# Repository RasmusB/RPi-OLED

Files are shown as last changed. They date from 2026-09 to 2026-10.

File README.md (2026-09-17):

# RPi-OLED Readme

Adapter board for using a generic OLED with a Raspberry Pi

> [!WARNING]
> Before using this repo, make sure to run the 'setup-hooks.sh' script first.

## Release notes

Releases are tagged using custom [Semantic Versioning rules](./Doc/SemVer%20Rules.md).

### 0.1.0

- TODO: List features that are introduced / removed
  - Focus on changes that would affect the end user, and indicate *how* they will be affected.
  - For example, don't write 'R2 changed to pull-down', but instead: 'Board will enter the bootloader when the user pushes SW1'.
  - More detailed change notes goes into the version history table in the schematic.

## Git behaviour

There are some pre-commit hooks in the .git folder. These will attempt to enforce a few sanity rules based on the following rules.

### The `main` branch must only contain releases of production files

- Commits to `main` are not allowed
- TODO: Commits must be tagged to generate production files (at least on the main branch)
- TODO: Tags must follow the pattern `vX.Y.Z` (see the [SemVer rules](./Doc/SemVer%20Rules.md) for details)

### Development happens in a `dev` branch

- All check-ins during development are made on the `dev` branch. The `dev` branch is merged into `main` when (and only when) the production files are ready for release.
- Any tags created on the dev branch *must not* match the pattern `vX.Y.Z` to ensure they are not confused for proper release tags
- Merging to main is not allowed if there are any failing tests (ERC, DRC, etc.)

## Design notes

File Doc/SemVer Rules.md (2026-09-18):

# SemVer Rules

These are the guidelines to determine the next tag number. Tags are validated against [this regex](https://regex101.com/r/iSM7DD/2).

## Major changes

This is used for major changes in mechanical or electrical behaviour that makes the board *incompatible* with previous use cases.

- Changes in the outline and/or component placement that makes the new version incompatible with existing enclosures
- Electrical changes in IO interfaces that makes the board incompatible with auxiliary equipment used with the last version
- Adding a end user interface

## Minor changes

This is meant for smaller changes that are meant to be included in the next production batch. The production release files will always have '0' as the patch revision.

- Any changes to the PCB: changed routing, stackup, board finish etc.
- Mechanical changes that does not cause mechanical issues
- BOM changes

## Patches

These are any patches that have been applied to a production board. It can be thought of as a simple issue tracker to document what needs to be updated before the next release of production files.

- Swapped components
- Changed solder jumpers
- Cut/patched traces
- Installed THT components

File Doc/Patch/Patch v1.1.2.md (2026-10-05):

# RPi-OLED Adapter v1.1.1 Patches

```foam-query
filter:
  and:
    - tag: "#errata"
    - jexl: "'v1.1.2' in resource.properties.patched_in"
select:
  - field: title
  - field: properties.workaround
    label: Immediate Workaround / Patch
  - field: properties.fixed_in
    label: Fixed in
format: table

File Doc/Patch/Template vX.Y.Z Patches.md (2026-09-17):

# [Project name] [vX.Y.Z] Patches

Example patch below

## Change I2C pullups

The I2C bus does not work reliably.

### Instructions

Change R1 and R2 according to BOM

[Image showing component placement if needed]

### BOM

| Designator | Old MPN | New MPN |
| --- | --- | --- |
| R1, R2 | RES04021k00 | RES04024k70 |

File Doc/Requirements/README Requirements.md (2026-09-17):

# README Requirements

## Naming and versioning

The requirements document shall be named as:

`[Project Name] Requirements v1.0.0`

The version in the filename indicates the version of the document itself and does not necessarily track the release tags, but there is some correlation:

- The **major** part increases when there are changes that force a new major release of the board.
- The **minor** part is updated for most other changes - new requirements, changed acceptance criteria etc.
- The **subrevision** is updated for any changes that don't affect the technical requirements or implementation. This can include (but is not limited to) spelling and formatting.

All requirements shall be numbered according to their category. A number is never reused - if a specific requirement becomes obsolete, it is instead marked as such.

## Requirement tags

There are some markers on each requirement.

### Validation level

| Tag |

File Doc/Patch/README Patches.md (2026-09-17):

# README Patches

New patch notes are created with the following file name pattern:

`[Project Name] [Tag] Patches.md`

Where `[Project Name]` is the name of the repository, and `[Tag]` is the version number of the board *after* applying the patch, i.e. `v1.2.3`. There should never be a 'patch 0', since that is reserved for release packages.

## Example content

```text
.
└── [Project name]
    └── Doc
        └── Patch
            ├── [Project name] v1.0.1 Patch.md
            ├── [Project name] v1.1.1 Patch.md
            ├── [Project name] v1.2.1 Patch.md
            └── ...
```

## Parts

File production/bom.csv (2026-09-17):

Designator | Footprint | Quantity | Value | LCSC Part #
C1, C2, C3, C4, C5, C6, C7 | 0402 | 7 | 100n | C1525
J1 | PinSocket_2x20_P2.54mm_Vertical | 1 | GPIO
J2 | Hirose_FH12-22S-0.5SH_1x22-1MP_P0.50mm_Horizontal | 1 | DSI IN | C597981
J9 | Hirose_FH26-39S-0.3SHW_2Rows-39Pins-1MP_P0.60mm_Horizontal | 1 | OLED_H497TLB01 | C92280
R1, R2, R7, R8 | 0402 | 4 | 3.9k | C11925
R3, R5 | 0402 | 2 | 10k | C25531
R4, R6 | 0402 | 2 | 12k1 | C25852
U1 | SOIC-8_5.3x5.3mm_P1.27mm | 1 | CAT24C256 | C79987
U2 | VSSOP-8_3x3mm_P0.65mm | 1 | TCA9800 | C2677364
U3 | SOT-23-5 | 1 | TPS76318 | C7099
U4 | SOT-23-6 | 1 | TPS22917DBV | C2681320

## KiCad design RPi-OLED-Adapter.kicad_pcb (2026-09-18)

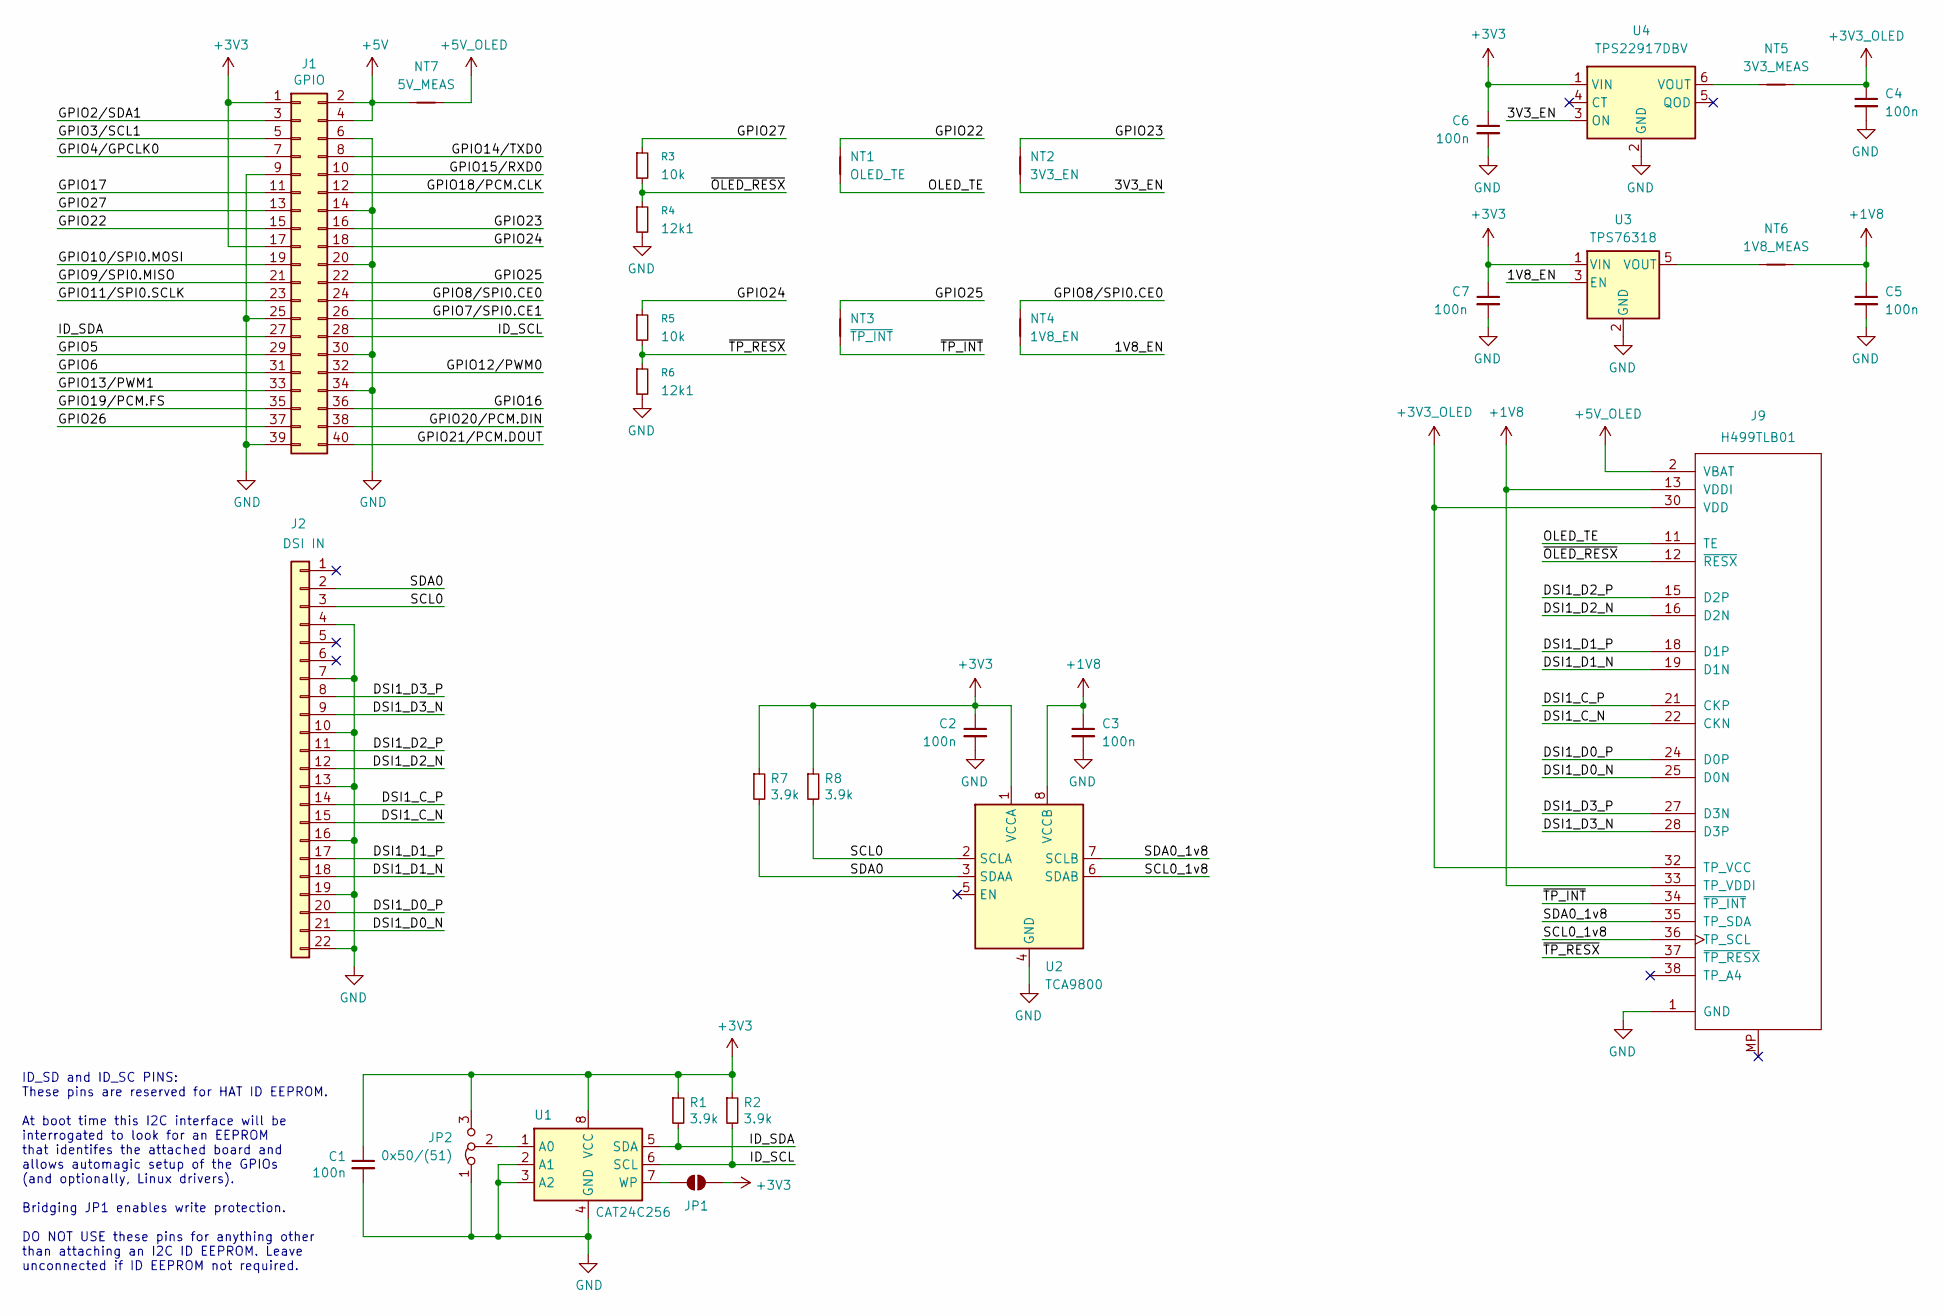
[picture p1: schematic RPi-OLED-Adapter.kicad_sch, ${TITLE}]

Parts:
C1, C2, C3, C4, C5, C6, C7: 100n; C_0402_1005Metric; MPN CL05B104KO5NNNC; LCSC Part # C1525
J1: GPIO; PinSocket_2x20_P2.54mm_Vertical; MPN 2541FV-2x20P-B; LCSC Part # C25503128
J2: DSI IN; Hirose_FH12-22S-0.5SH_1x22-1MP_P0.50mm_Horizontal; MPN FH12-22S-0.5SH(55); LCSC Part # C597981
J9: H499TLB01; Hirose_FH26-39S-0.3SHW_2Rows-39Pins-1MP_P0.60mm_Horizontal; MPN FH26W-39S-0.3SHW(60); LCSC Part # C92280
JP1: ID_WP; SolderJumper-2_P1.3mm_Bridged_RoundedPad1.0x1.5mm
JP2: 0x50/(51); SolderJumper-3_P1.3mm_Bridged12_RoundedPad1.0x1.5mm
NT1: OLED_TE; SolderJumper-2_P1.3mm_Bridged_RoundedPad1.0x1.5mm
NT2: 3V3_EN; SolderJumper-2_P1.3mm_Bridged_RoundedPad1.0x1.5mm
NT3: ~{TP_INT}; SolderJumper-2_P1.3mm_Bridged_RoundedPad1.0x1.5mm
NT4: 1V8_EN; SolderJumper-2_P1.3mm_Bridged_RoundedPad1.0x1.5mm
NT5: 3V3_MEAS; SolderJumper-2_P1.3mm_Bridged_RoundedPad1.0x1.5mm
NT6: 1V8_MEAS; SolderJumper-2_P1.3mm_Bridged_RoundedPad1.0x1.5mm
NT7: 5V_MEAS; SolderJumper-2_P1.3mm_Bridged_RoundedPad1.0x1.5mm
R1, R2, R7, R8: 3.9k; R_0402_1005Metric; MPN 0402WGJ0392TCE; LCSC Part # C11925
R3, R5: 10k; R_0402_1005Metric; MPN 0402WGJ0103TCE; LCSC Part # C25531
R4, R6: 12k1; R_0402_1005Metric; MPN 0402WGF1212TCE; LCSC Part # C25852
U1: CAT24C256; SOIC-8_5.3x5.3mm_P1.27mm; MPN CAT24C256WI-GT3; LCSC Part # C79987
U2: TCA9800; VSSOP-8_3x3mm_P0.65mm; MPN TCA9800DGKR; LCSC Part # C2677364
U3: TPS76318; SOT-23-5; MPN TPS76318DBVR; LCSC Part # C7099
U4: TPS22917DBV; SOT-23-6; MPN TPS22917DBVR; LCSC Part # C2681320

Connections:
+1V8: C3.1, C5.1, J9.13 (VDDI), J9.33 (TP_VDDI), NT6.2, U2.8 (VCCB)
+3V3: C1.1, C2.1, C6.1, C7.1, J1.1, J1.17, JP1.2 (B), JP2.3 (B), R1.1, R2.1, R7.1, R8.1, U1.8 (VCC), U2.1 (VCCA), U3.1 (VIN), U4.1 (VIN)
+3V3_OLED: C4.1, J9.30 (VDD), J9.32 (TP_VCC), NT5.2
+5V: J1.2, J1.4, NT7.1
+5V_OLED: J9.2 (VBAT), J9.3 (VBAT), J9.4 (VBAT), J9.5 (VBAT), J9.6 (VBAT), NT7.2
/1V8_EN: NT4.1, U3.3 (EN)
/3V3_EN: NT2.1, U4.3 (ON)
/DSI1_C_N: J2.15, J9.22 (CKN)
/DSI1_C_P: J2.14, J9.21 (CKP)
/DSI1_D0_N: J2.21, J9.25 (D0N)
/DSI1_D0_P: J2.20, J9.24 (D0P)
/DSI1_D1_N: J2.18, J9.19 (D1N)
/DSI1_D1_P: J2.17, J9.18 (D1P)
/DSI1_D2_N: J2.12, J9.16 (D2N)
/DSI1_D2_P: J2.11, J9.15 (D2P)
/DSI1_D3_N: J2.9, J9.28 (D3P)
/DSI1_D3_P: J2.8, J9.27 (D3N)
/GPIO2/SDA1: J1.3
/GPIO3/SCL1: J1.5
/GPIO4/GPCLK0: J1.7
/GPIO5: J1.29
/GPIO6: J1.31
/GPIO7/SPI0.CE1: J1.26
/GPIO8/SPI0.CE0: J1.24, NT4.2
/GPIO9/SPI0.MISO: J1.21
/GPIO10/SPI0.MOSI: J1.19
/GPIO11/SPI0.SCLK: J1.23
/GPIO12/PWM0: J1.32
/GPIO13/PWM1: J1.33
/GPIO14/TXD0: J1.8
/GPIO15/RXD0: J1.10
/GPIO16: J1.36
/GPIO17: J1.11
/GPIO18/PCM.CLK: J1.12
/GPIO19/PCM.FS: J1.35
/GPIO20/PCM.DIN: J1.38
/GPIO21/PCM.DOUT: J1.40
/GPIO22: J1.15, NT1.2
/GPIO23: J1.16, NT2.2
/GPIO24: J1.18, R5.1
/GPIO25: J1.22, NT3.2
/GPIO26: J1.37
/GPIO27: J1.13, R3.1
/ID_SCL: J1.28, R2.2, U1.6 (SCL)
/ID_SDA: J1.27, R1.2, U1.5 (SDA)
/OLED_TE: J9.11 (TE), NT1.1
/SCL0: J2.3, R8.2, U2.2 (SCLA)
/SCL0_1v8: J9.36 (TP_SCL), U2.6 (SDAB)
/SDA0: J2.2, R7.2, U2.3 (SDAA)
/SDA0_1v8: J9.35 (TP_SDA), U2.7 (SCLB)
/~OLED_RESX: J9.12 (~RESX), R3.2, R4.1
/~TP_INT: J9.34 (~TP_INT), NT3.1
/~TP_RESX: J9.37 (~TP_RESX), R5.2, R6.1
GND: C1.2, C2.2, C3.2, C4.2, C5.2, C6.2, C7.2, J1.6, J1.9, J1.14, J1.20, J1.25, J1.30, J1.34, J1.39, J2.4, J2.7, J2.10, J2.13, J2.16, J2.19, J2.22, J9.1 (GND), J9.7 (GND), J9.8 (GND), J9.9 (GND), J9.14 (GND), J9.17 (GND), J9.20 (GND), J9.23 (GND), J9.26 (GND), J9.29 (GND), J9.31 (GND), J9.39 (GND), JP2.1 (A), R4.2, R6.2, U1.2 (A1), U1.3 (A2), U1.4 (GND), U2.4 (GND), U3.2 (GND), U4.2 (GND)
unnamed: JP1.1 (A), U1.7 (WP)
unnamed: JP2.2 (C), U1.1 (A0)
unnamed: NT6.1, U3.5 (VOUT)
unnamed: NT5.1, U4.6 (VOUT)

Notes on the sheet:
ID_SD and ID_SC PINS: These pins are reserved for HAT ID EEPROM. At boot time this I2C interface will be interrogated to look for an EEPROM that identifes the attached board and allows automagic setup of the GPIOs (and optionally, Linux drivers). Bridging JP1 enables write protection. DO NOT USE th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

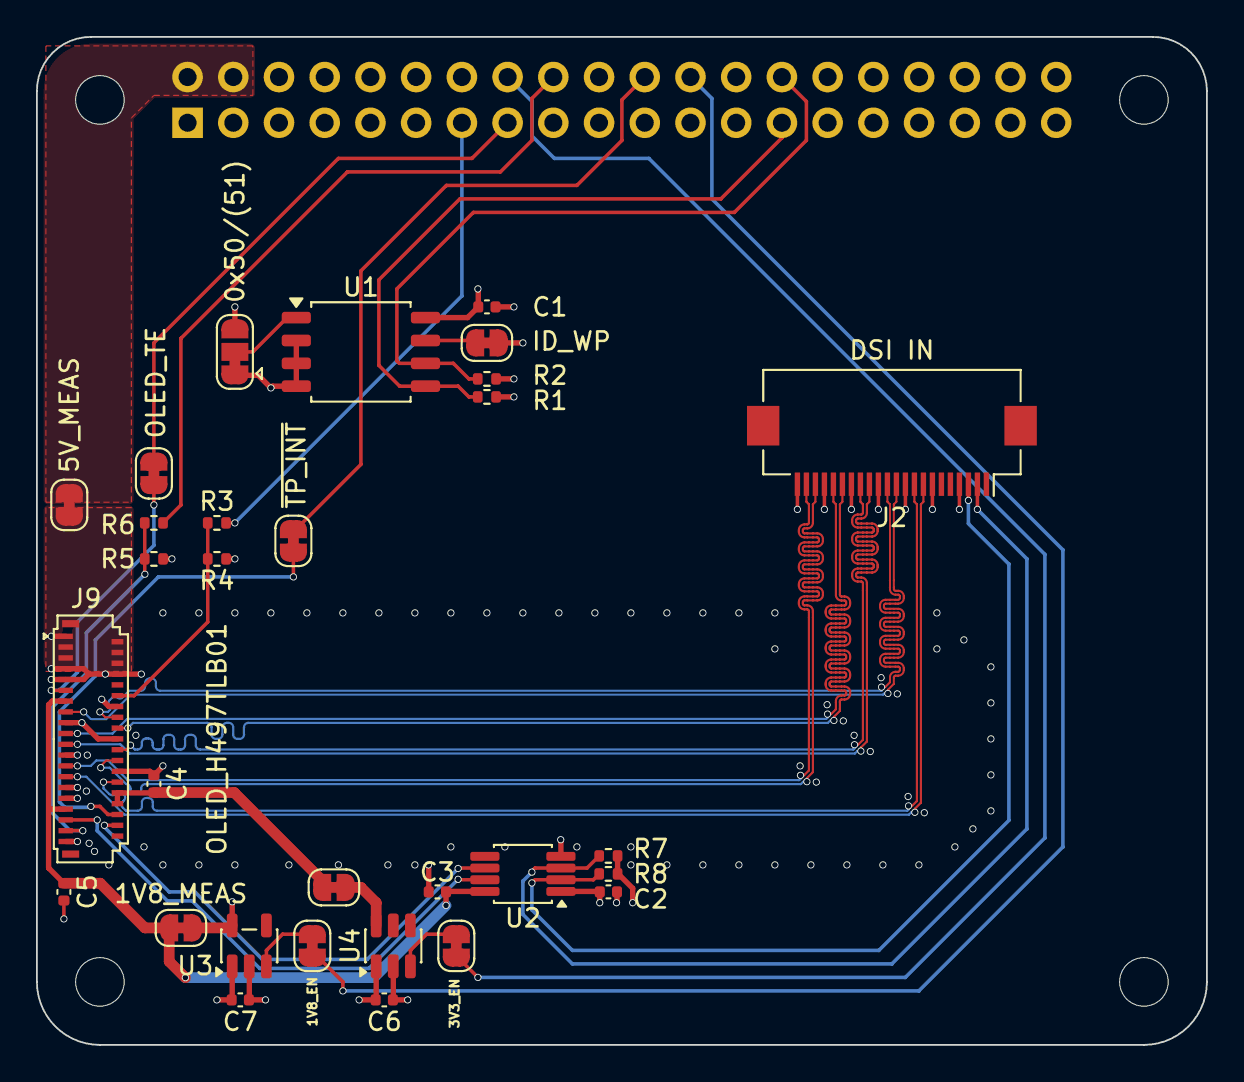
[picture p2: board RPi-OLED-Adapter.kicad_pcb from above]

Board: 4 copper layers, 65.0 x 56.0 mm, 35 parts (1 on the bottom side), 38 nets.

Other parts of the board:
MH1, MH2, MH3, MH4: MountingHole_2.7mm_M2.5

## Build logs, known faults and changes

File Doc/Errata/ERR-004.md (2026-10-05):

---
tags: ["errata"]
id: ERR-004
status: open # open | workaround-available | resolved
severity: major # critical | major | minor
affected_revisions: ["v1.0.0", "v1.1.0"]
workaround: Ignore what the schematic says
patched_in:
fixed_in: 
---

# ERR-004: OLED footprint has wrong pinout

Pins 27 and 28 does not match the polarity that the other DSI signal pairs has. In the schematic, the polarity was reversed anyway, so the error canceled itself out.

## Cause

Error in the (preliminary) datasheet used during development.

## Fix

Fix the footprint before using it in another board.

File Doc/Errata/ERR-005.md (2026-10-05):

---
tags: ["errata"]
id: ERR-005
status: workaround-avaliable # open | workaround-available | resolved
severity: major # critical | major | minor
affected_revisions: ["v1.0.0", "v1.1.0"]
workaround: Swap SCL and SDA on 1v8 side
patched_in: ["v1.1.2"]
fixed_in: 
---

# ERR-005: I2C signals reversed on 1v8 side

I2C signals coming out of U2 are reversed.

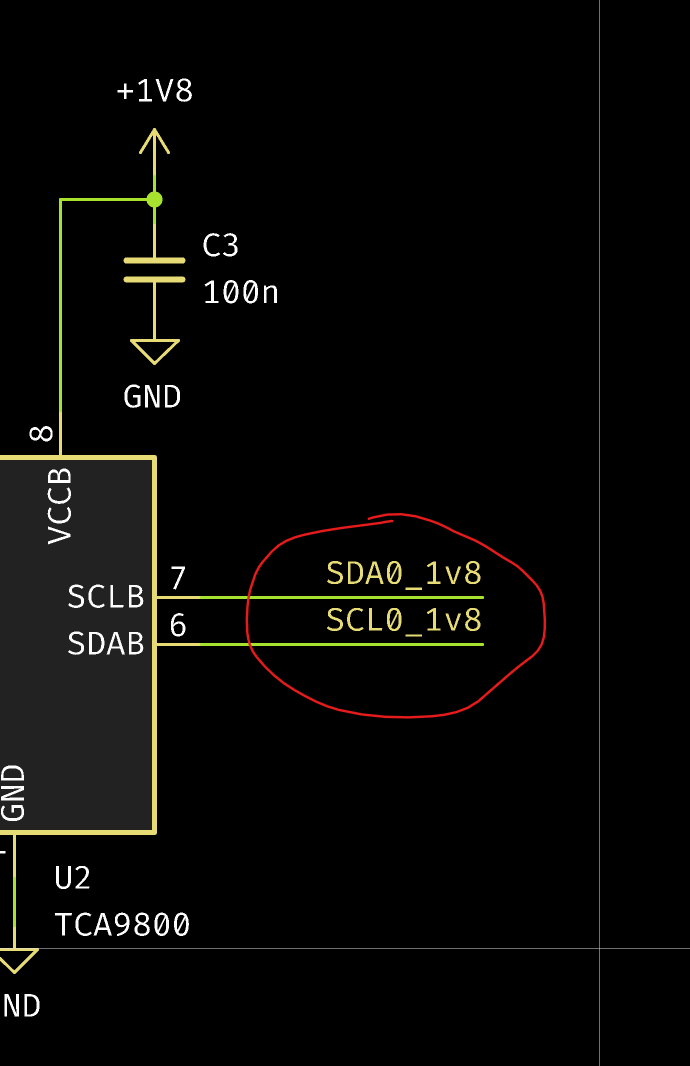
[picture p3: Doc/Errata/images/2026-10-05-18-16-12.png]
SDA and SCL should switch places


## Cause

Human error.

## Patch

Cut the traces and solder in bodge wires on the 1v8 side.

## Fix

Move the signals to the correct pins.

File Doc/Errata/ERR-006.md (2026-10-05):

---
tags: ["errata"]
id: ERR-006
status: workaround-avaliable # open | workaround-available | resolved
severity: major # critical | major | minor
affected_revisions: ["v1.0.0", "v1.1.0"]
workaround: Cut solder jumper JP1
patched_in: ["v1.1.2"]
fixed_in: 
---

# ERR-006: EEPROM is permanently write protected

In the schematic, JP1 shows an open solder jumper. But the wrong footprint was used, so it is really connected, pulling the WP pin into the write protected state.

## Cause

Human error.

## Patch

Cut the JP1 solder jumper.

## Fix

Switch to the correct footprint.

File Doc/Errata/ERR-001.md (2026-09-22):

---
tags: ["errata"]
id: ERR-001
status: resolved # open | workaround-available | resolved
severity: critical # critical | major | minor
affected_revisions: ["v1.0.0"]
workaround: 
patched_in: 
fixed_in: v1.1.0
---

# ERR-001: Board edge keepout too small

The production files were rejected by JLCPCB. Apparently, the inner layer copper fills intersected with the board edge keepout, which is defined as `≧0.2mm` for routed edges[^1].

[^1]: [https://jlcpcb.com/capabilities/pcb-capabilities](https://jlcpcb.com/capabilities/pcb-capabilities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)

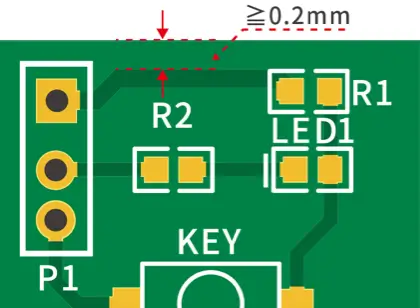
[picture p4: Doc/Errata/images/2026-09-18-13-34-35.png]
From jlcpcb.com


The issue arises at all four corners of the board as shown in the screenshort from JLCPCB.

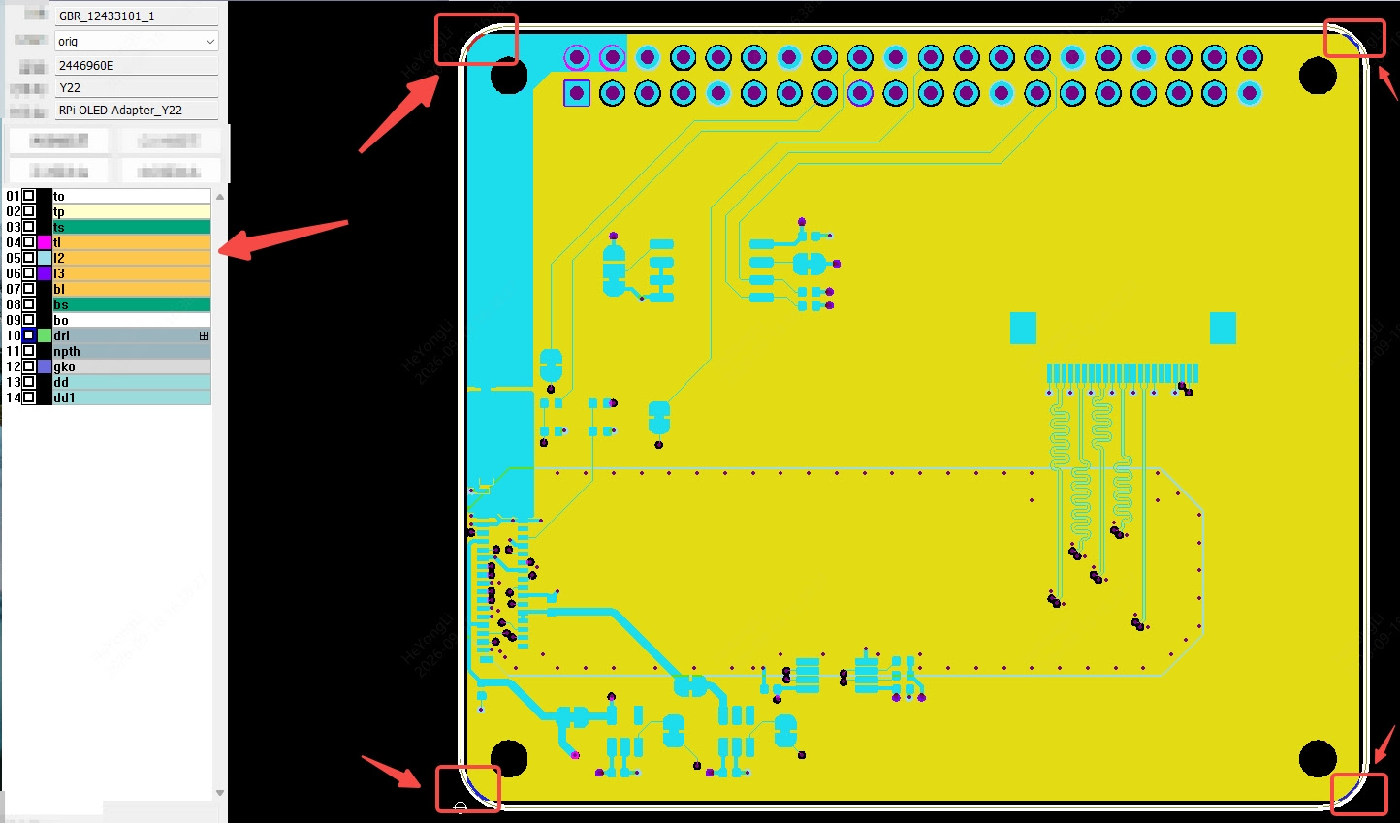
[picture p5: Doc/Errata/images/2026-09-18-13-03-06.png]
Screenshot from JLCPCB


## Cause

It seems KiCAD has a very small default value for `Copper to edge clearance`. It looked better along the edges because the zones had been offset 0.25mm from the board edge.

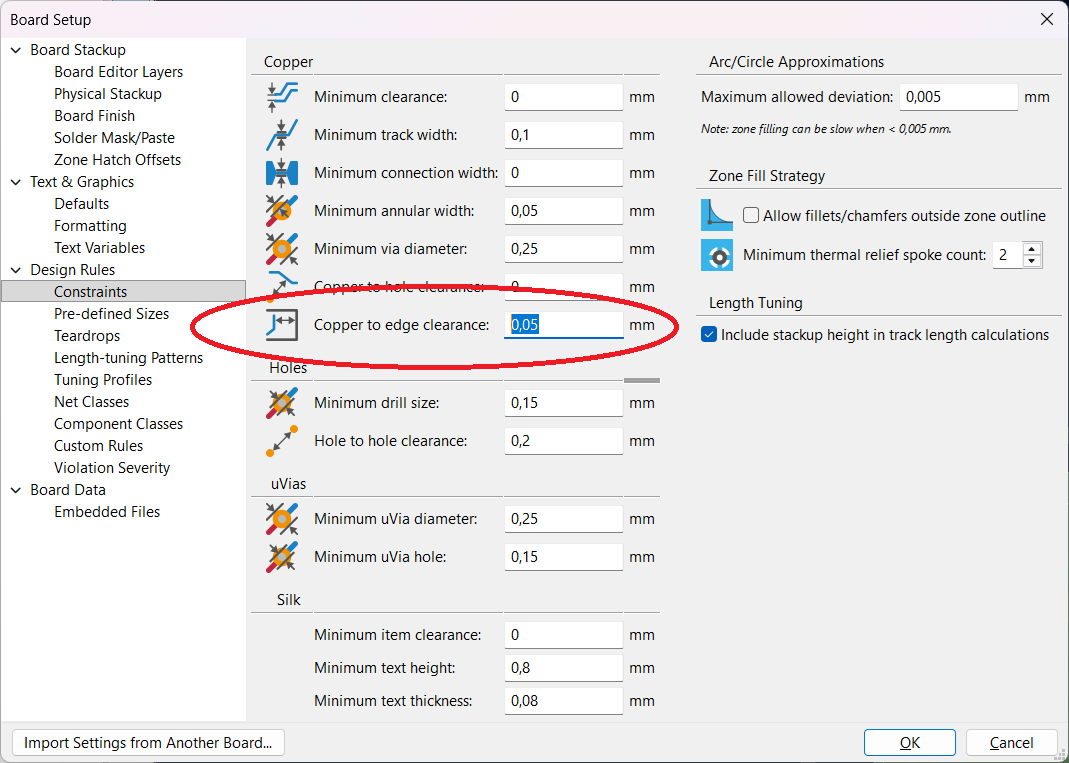
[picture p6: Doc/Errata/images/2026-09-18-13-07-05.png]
Screenshot from KiCAD


## Fix

Increase the clearance value to `0.50mm`.
Extend the zone border for all layers to follow the board edge exactly.

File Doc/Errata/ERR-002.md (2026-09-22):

---
tags: ["errata"]
id: ERR-002
status: resolved # open | workaround-available | resolved
severity: minor # critical | major | minor
affected_revisions: ["v1.0.0"]
workaround: 
patched_in: 
fixed_in: v1.1.0
---

# ERR-002: Board is missing markings

There are no markings on the board indicating board name or revision.

## Cause

Human error.

## Fix

Add correct markings for v1.1.0.

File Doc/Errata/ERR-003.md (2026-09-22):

---
tags: ["errata"]
id: ERR-003
status: workaround-available # open | workaround-available | resolved
severity: major # critical | major | minor
affected_revisions: ["v1.0.0", "v1.1.0"]
workaround: Change P/N for build
patched_in: ["v1.1.1"]
fixed_in: 
---

# ERR-003: Wrong footprint for U1

The board uses the 208 mil version of the SOIC-8 footprint, but the part number selected is the 150 mil version. As a consequence, the footprint is too small and this was flagged by JLCPCB.

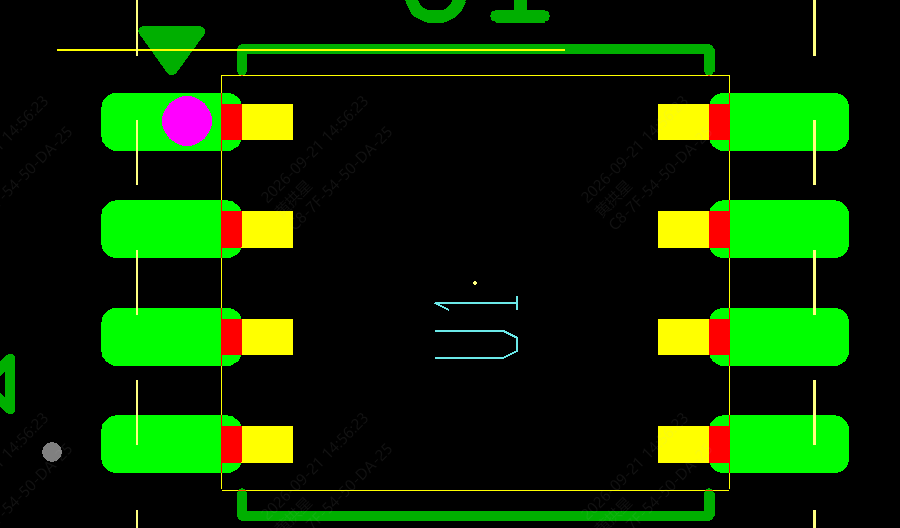
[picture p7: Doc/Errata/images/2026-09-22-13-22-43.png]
Screenshot showing footprint mismatch


## Cause

Human error.

## Patch

For the `v1.1.0` build, JLCPCB was instructed to instead use the part [C153760](https://jlcpcb.com/partdetail/onsemi-CAT24C512XIT2/C153760) which should be in a 208 mil SOIC-8 package. These boards are designated as `v1.1.1`.

## Fix

Update the board to instead use a 150 mil variant of the footprint.

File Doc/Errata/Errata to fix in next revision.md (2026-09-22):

# Errata to fix in next revision

```foam-query
filter:
  and:
    - tag: "#errata"
    - jexl: "resource.properties.fixed_in == null"
select:
  - field: title
  - field: properties.severity
    label: Severity
  - field: properties.status
    label: Status
  - field: properties.workaround
    label: Workaround Summary
sort: title ASC
format: table

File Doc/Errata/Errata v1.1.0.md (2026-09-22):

# RPi-OLED Adapter v1.1.0 Errata

```foam-query
filter:
  and:
    - tag: "#errata"
    - jexl: "'v1.1.0' in resource.properties.affected_revisions"
select:
  - field: title
  - field: properties.workaround
    label: Immediate Workaround / Patch
  - field: properties.patched_in
    label: Patched In
  - field: properties.fixed_in
    label: Fixed in
format: table

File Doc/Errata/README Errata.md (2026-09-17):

# README Errata

This folder is used to track any errata and/or deviations in the design.

This could be designs that fail to meet the requirements, conditions that have been observed to cause catastrophic failure, or anything else that might show up.

This is also where differences between production files and delivered boards are documented, such as MPN substitutions made by the manufacturer made - even if they haven't caused any issues.

Not every revision or patch note will have an errata.

## Example folder content

```text
.
└── [Project name]
    └── Doc
        └── Errata
            ├── [Project name] v1.0.0 Errata.md
            ├── [Project name] v1.1.0 Errata.md
            ├── [Project name] v1.2.1 Errata.md
            └── ...
```

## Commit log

2026-09-17 Commit first version
    [RPi-OLED-Adapter.kicad_pcb, RPi-OLED-Adapter.kicad_sch, bom.csv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]
2026-09-18 Create files for v1.1.0 release
    [RPi-OLED-Adapter.kicad_pcb, RPi-OLED-Adapter.kicad_sch]
